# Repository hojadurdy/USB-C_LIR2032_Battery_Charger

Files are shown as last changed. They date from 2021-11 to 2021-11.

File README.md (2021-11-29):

# USB-C LIR2032 Battery Charger

### What is it?
A lithium coin cell battery charger for charging LIR2032 rechargeable batteries. 

### Features:

- Standard 5V USB power input
- USB-C connector
- Separate charging IC for each battery
- Charging Voltage - 4.2V
- Charging Current - 13mA
- Undervoltage lockout
- Automatically cuts off power when the battery is fully charged
- Preconditioning and end-of-charge
- Preconditioning of low voltage batteries
- High accuracy preset output voltage regulation (+/-1.0%)
- Current monitoring
- Reverse discharge protection
- Green LED indicating input power
- Red LED indicating charging

### How to Use:
Slide the coin cell battery in the right way. Power the device with a USB port. The Green Power LED will turn on indicating it is getting power from the USB port. Red Charge LED will keep blinking if the battery is not inserted. When the battery is charging, the Red Charge LED will stay on. The Red LED will turn off to let you know when it is fully charged.

### NOTE:

- Only for use with rechargeable LIR2032 cells!
- Do not try to recharge non-rechargeable Lithium coin cell batteries like CR2032!
- Do not charge unattended
- Do not charge damaged cells
- Do not insert the battery in reverse polarity

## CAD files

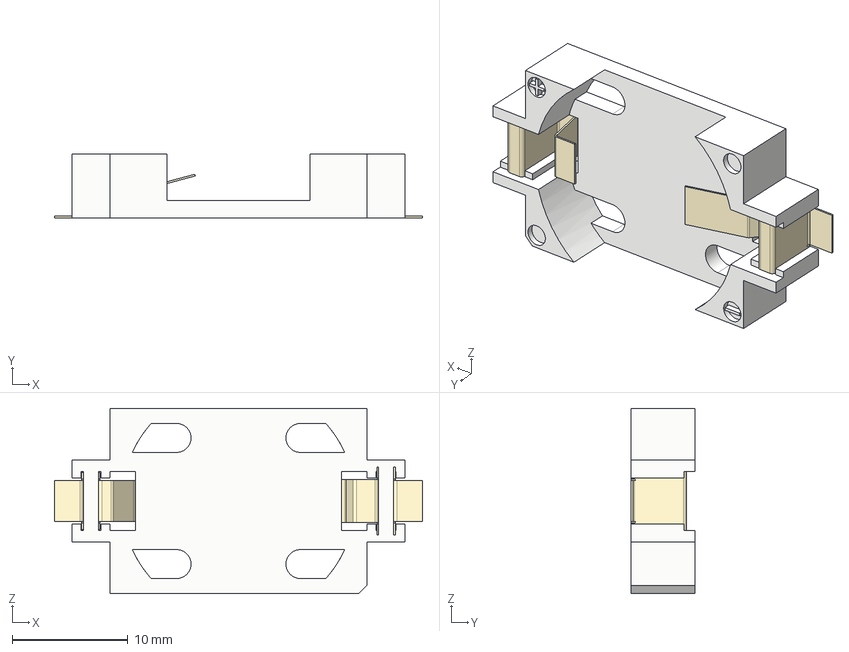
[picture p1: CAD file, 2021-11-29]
3D/CR2032_Plastic_Holder.step
31.8 x 5.50 x 16.0 mm
base
connector_plus
connector_minus

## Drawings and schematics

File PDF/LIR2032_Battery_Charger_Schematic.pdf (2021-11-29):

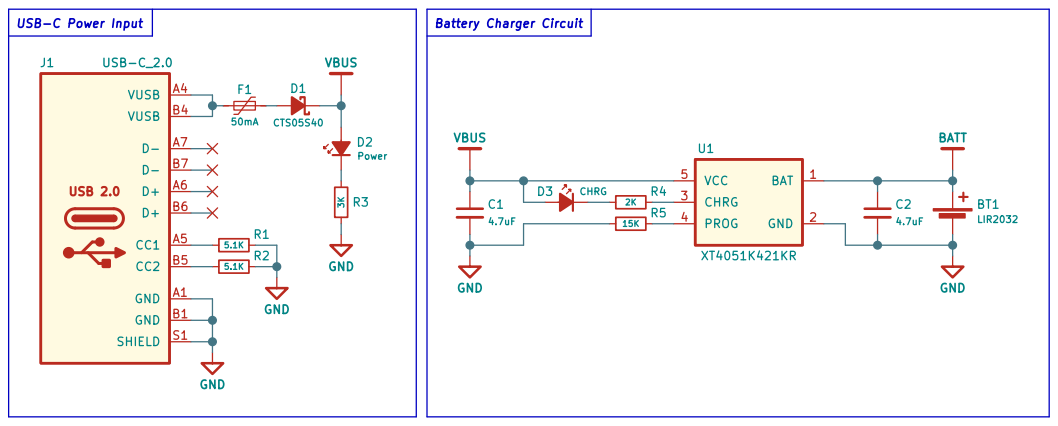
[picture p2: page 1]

Curious Design Labs | Hojadurdy Durdygylyjov
Charger for Single LIR2032 Li-Ion Coin Cell Battery License: CC BY-SA 4.0 Sheet: 1/1

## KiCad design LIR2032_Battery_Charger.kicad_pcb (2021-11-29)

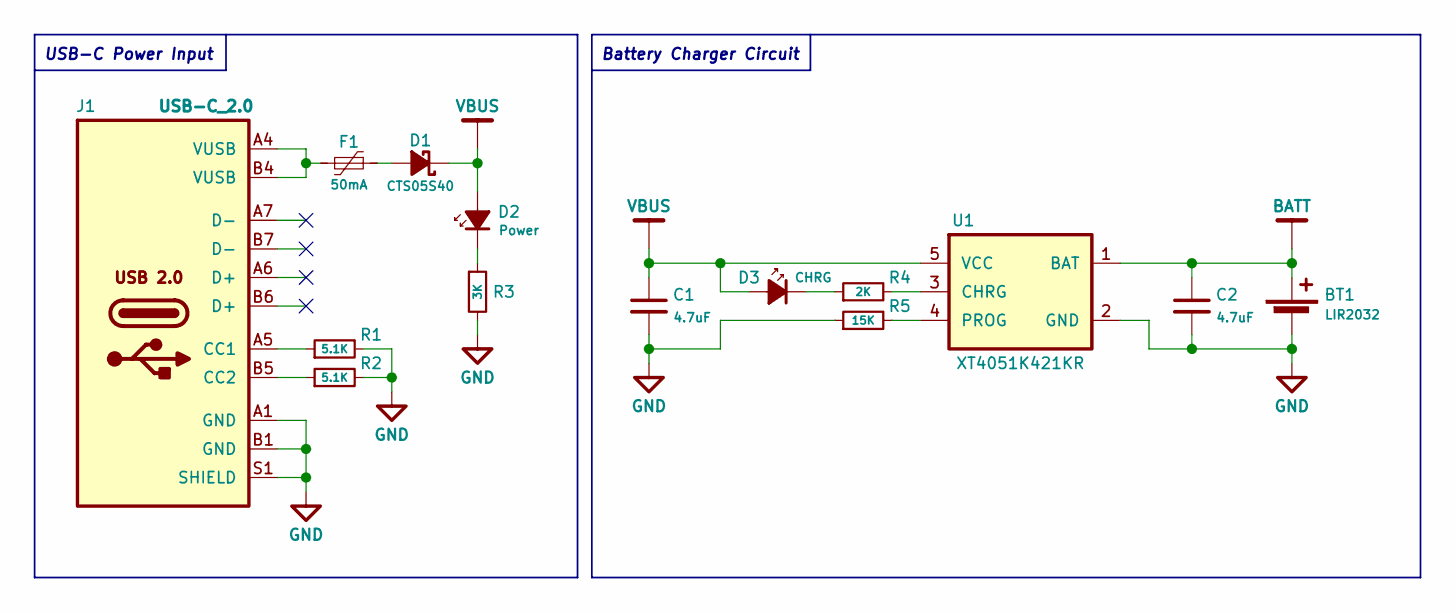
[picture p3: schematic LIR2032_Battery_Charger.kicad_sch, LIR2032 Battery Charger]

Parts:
BT1: LIR2032; BatteryHolder_Keystone_1060_1x2032
C1, C2: 4.7uF; C_0402_1005Metric
D1: CTS05S40; CST2
D2: Power; LED_0402_1005Metric
D3: CHRG; LED_0402_1005Metric
F1: 50mA; Fuse_0402_1005Metric
J1: USB-C_2.0; HRO_TYPE-C-31-M-12
R1, R2: 5.1K; R_0402_1005Metric
R3: 3K; R_0402_1005Metric
R4: 2K; R_0402_1005Metric
R5: 15K; R_0402_1005Metric
U1: XT4051K421KR; SOT-553

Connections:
BATT: BT1.1 (+), C2.1, U1.1 (BAT)
GND: BT1.2 (-), C1.2, C2.2, J1.A1 (GND), J1.B1 (GND), J1.S1 (SHIELD), R1.2, R2.2, R3.2, R5.1, U1.2 (GND)
unnamed: D1.2 (A), F1.1
unnamed: D2.1 (K), R3.1
unnamed: F1.2, J1.A4 (VUSB), J1.B4 (VUSB)
unnamed: J1.A5 (CC1), R1.1
unnamed: J1.B5 (CC2), R2.1
unnamed: D3.1 (K), R4.1
unnamed: R4.2, U1.3 (CHRG)
unnamed: R5.2, U1.4 (PROG)
VBUS: C1.1, D1.1 (K), D2.2 (A), D3.2 (A), U1.5 (VCC)

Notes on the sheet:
USB-C Power Input
Battery Charger Circuit

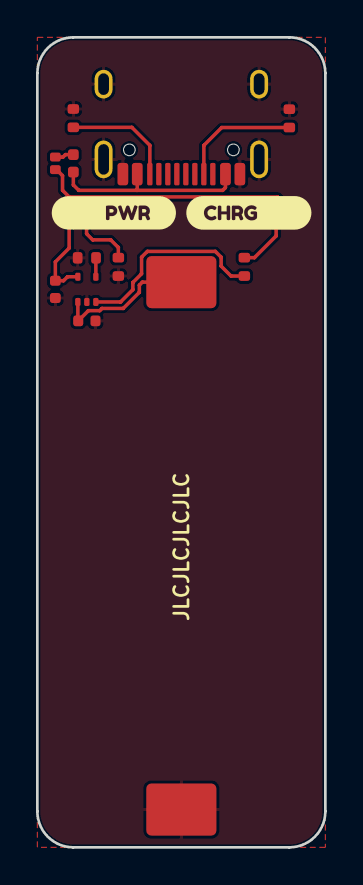
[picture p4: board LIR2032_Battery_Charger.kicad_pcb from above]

Board: 2 copper layers, 16.0 x 45.0 mm, 16 parts (0 on the bottom side), 11 nets.

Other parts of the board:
kibuzzard-6192C1BF: G***; kibuzzard-6192C1BF
kibuzzard-6192C1F3: G***; kibuzzard-6192C1F3
